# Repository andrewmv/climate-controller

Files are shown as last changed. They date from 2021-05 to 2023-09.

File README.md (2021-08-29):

# Home Assistant Climate Controller

A wifi-enabled replacement for line-level electric heat controller thermostats installed in standard single-gang US electrical junction boxes

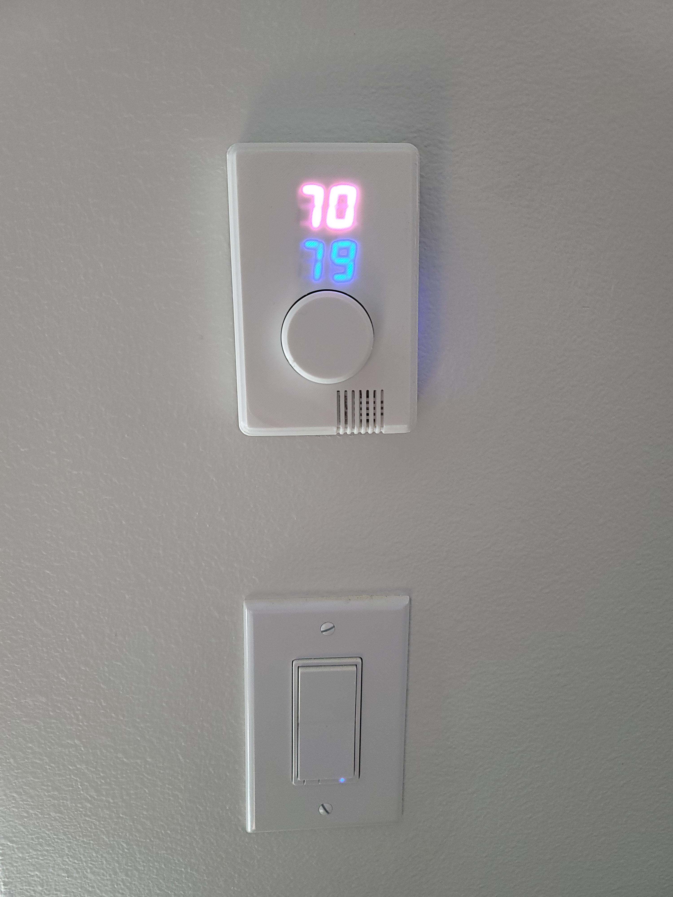
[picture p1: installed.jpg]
installed


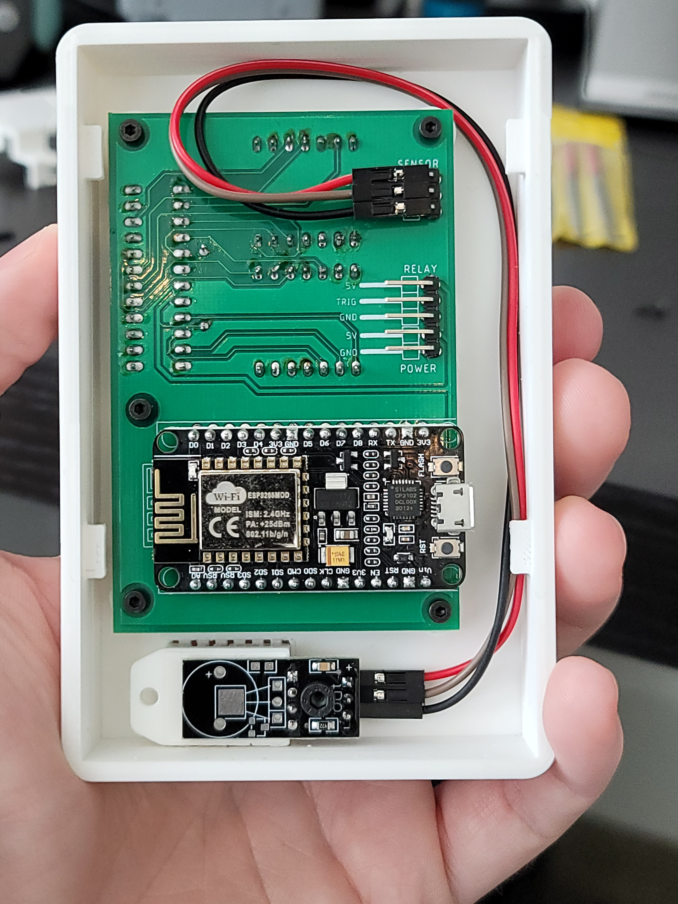
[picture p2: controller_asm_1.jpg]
controller_asm_1


## Enclosure

OpenSCAD sources and rendered STLs for 3D printing

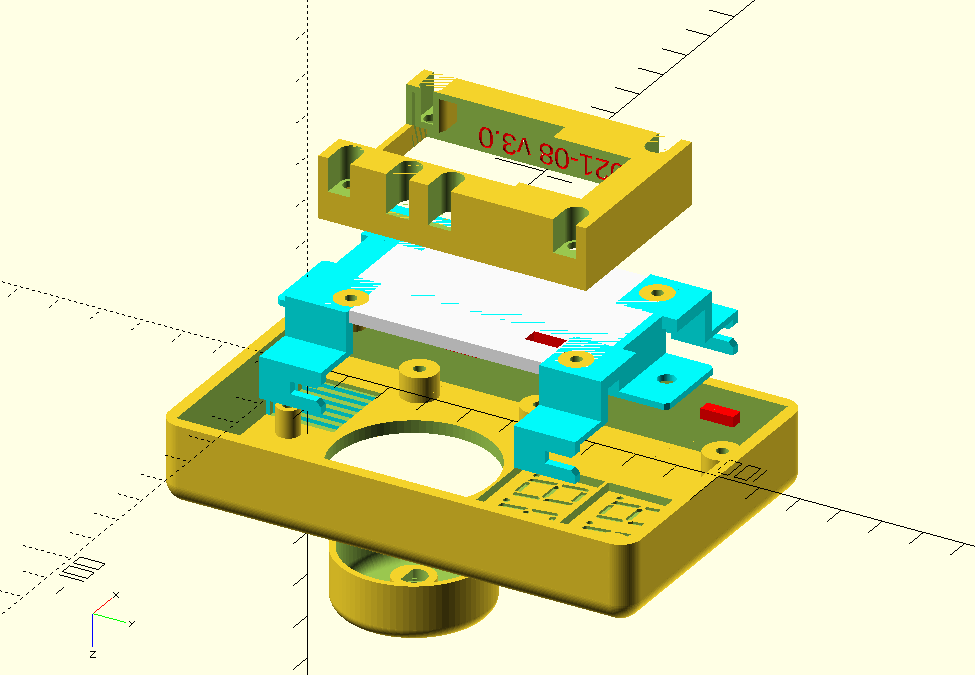
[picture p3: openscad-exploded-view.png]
openscad-exploded-view


## PCB

EagleCAD schematics, boards, and reqresuite libraries.

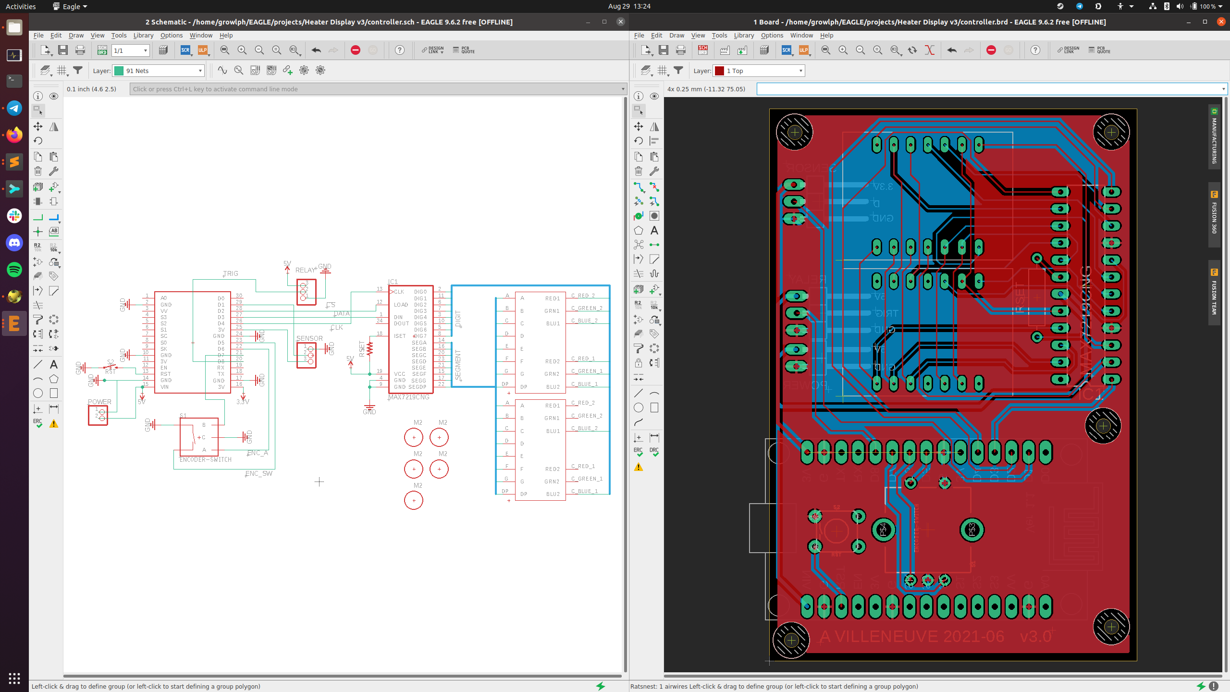
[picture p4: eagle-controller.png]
eagle-controller


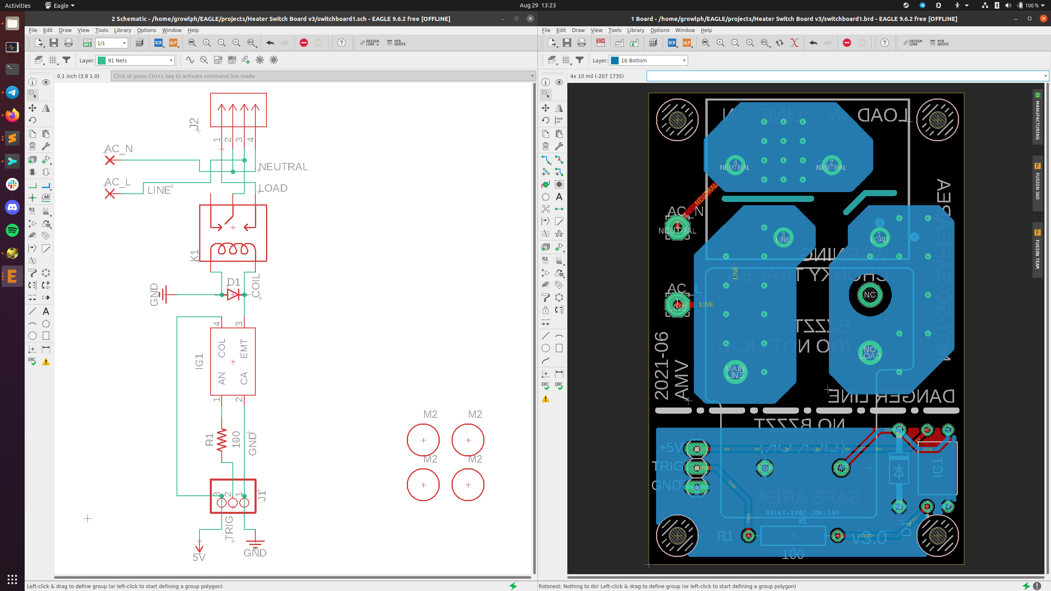
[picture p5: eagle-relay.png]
eagle-relay


## Software

Control software for ESPHome.io

## Reference

Part datasheets and vendor libraries

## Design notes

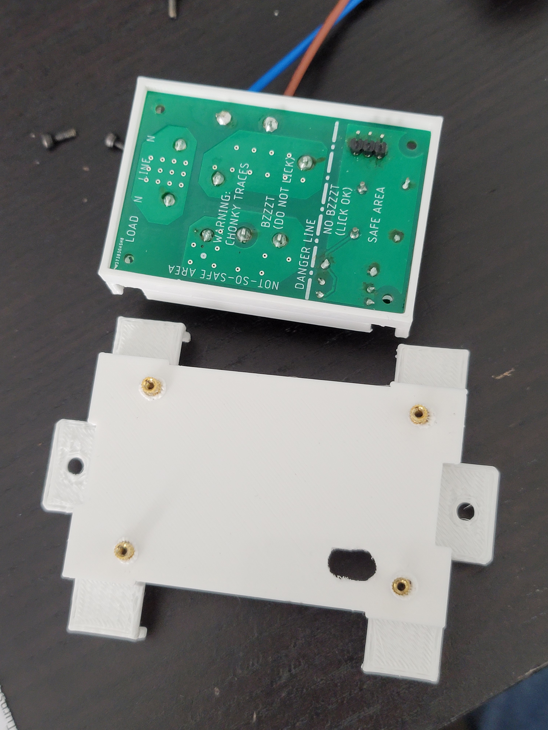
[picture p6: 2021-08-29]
relay_asm_1.jpg

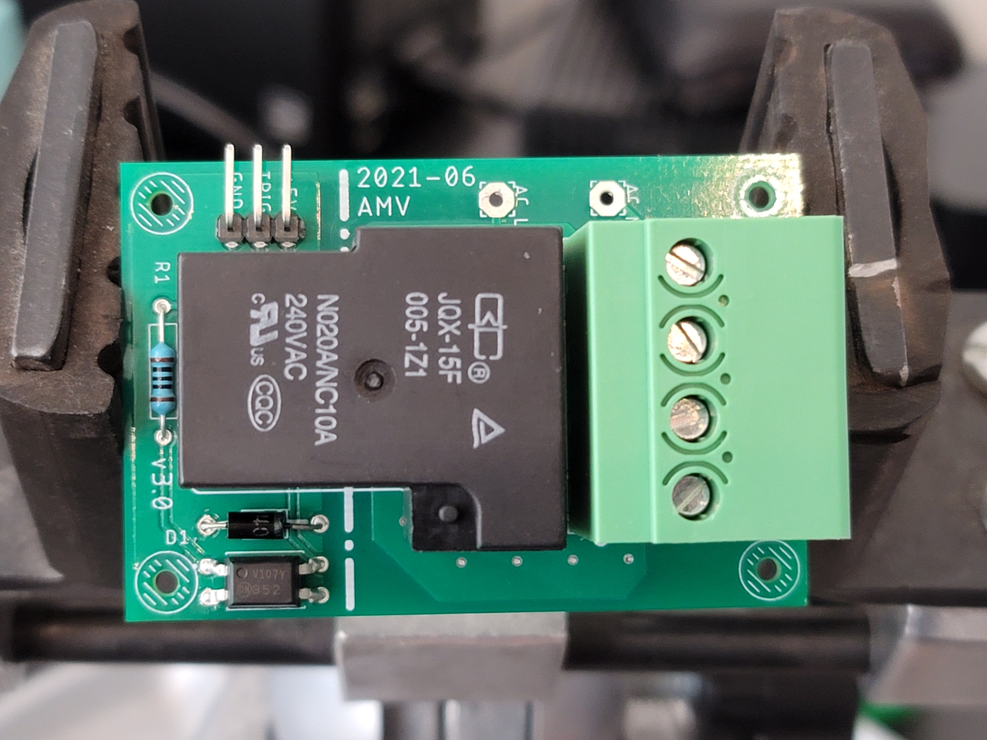
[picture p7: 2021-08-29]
finished_pop_relay_pcb.jpg

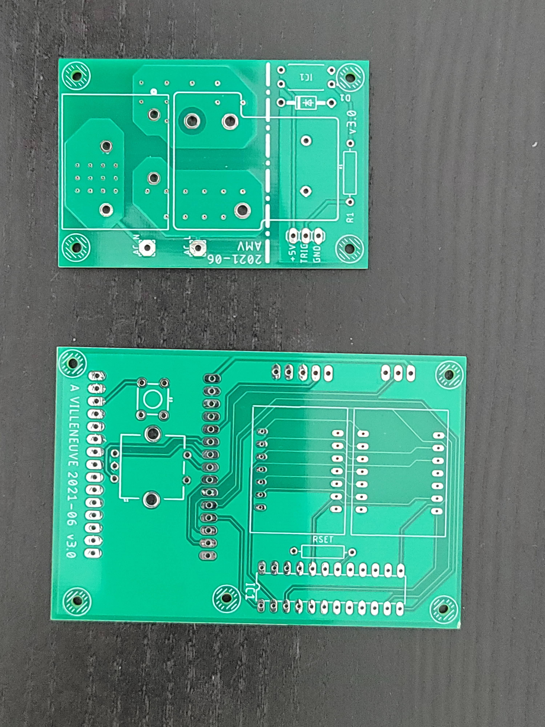
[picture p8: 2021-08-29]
finished_unpop_pcb.jpg

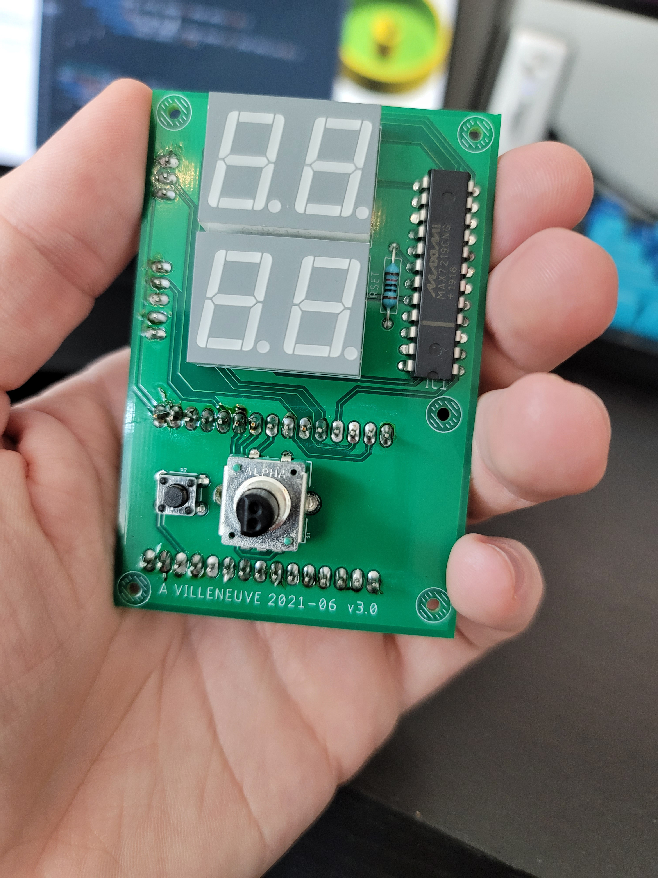
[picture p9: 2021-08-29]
finished_pop_cont_pcb.jpg

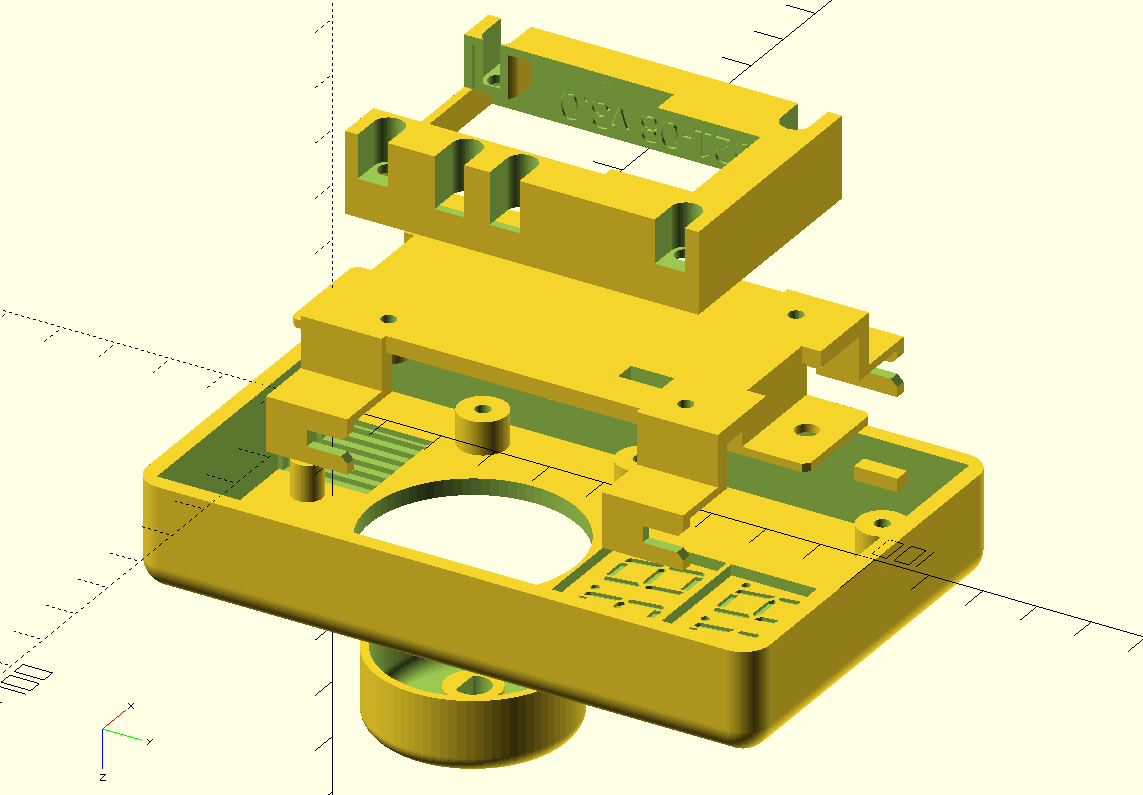
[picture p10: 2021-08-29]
openscad-explode-rendered.png

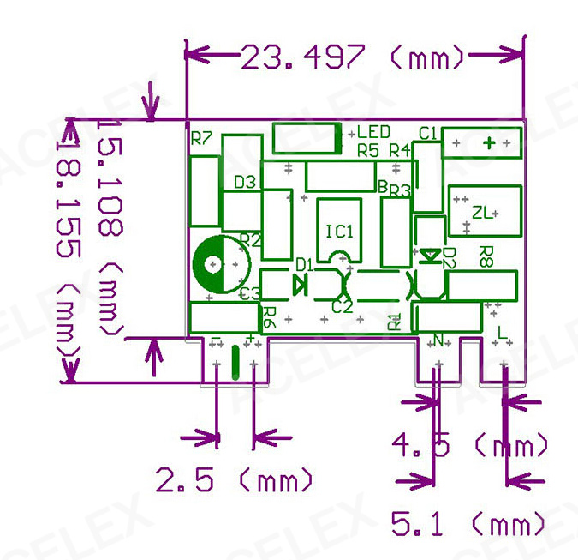
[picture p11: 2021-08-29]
Reference/PSU Dimensions.png

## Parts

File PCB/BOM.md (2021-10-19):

# Bill of Materials

| Quantity | Part | Link |
| --- | --- | --- |
| 1 | Maxim MAX7219 DIP | https://www.adafruit.com/product/453 |
| 1 | ACD8143 Segment Display | https://www.sparkfun.com/products/13999 |
| 1 | Subminiature tactile switch | https://www.sparkfun.com/products/97 |
| 3 | 0.1" headers (straight) | https://www.sparkfun.com/products/116 |
| 8 | 0.1" headers (right angle) | https://www.sparkfun.com/products/553 |
| 1 | ESP8266 Development board | https://www.amazon.com/gp/product/B07HF44GBT/ |
| 1 | FOD852300 Optoisolator | https://www.digikey.com/en/products/detail/onsemi/FOD852300/1054006 |
| 1 | Phoenix Contact 6.35mm terminal block connector | https://www.digikey.com/en/products/detail/phoenix-contact/1017516/9346596 |
| 1 | 20A Relay | https://www.sparkfun.com/products/10924 |
| 1 | Rotary Encoder | https://www.sparkfun.com/products/9117 |
| 1 | Axial Diode | |
| 1 | 100Ω Axial Resistor | |
| 1 | 33kΩ Axial Resistor | |
| 5 | M2 x 3mm brass threaded inserts | https://www.amazon.com/gp/product/B07LBQFNQD/ |
| 4 | M2 x 8mm brass threaded inserts | |
| 9 | M2 x 6mm screws | https://www.amazon.com/gp/product/B01FL88Y76/ |
| 1 | M3 x 6mm screw | |

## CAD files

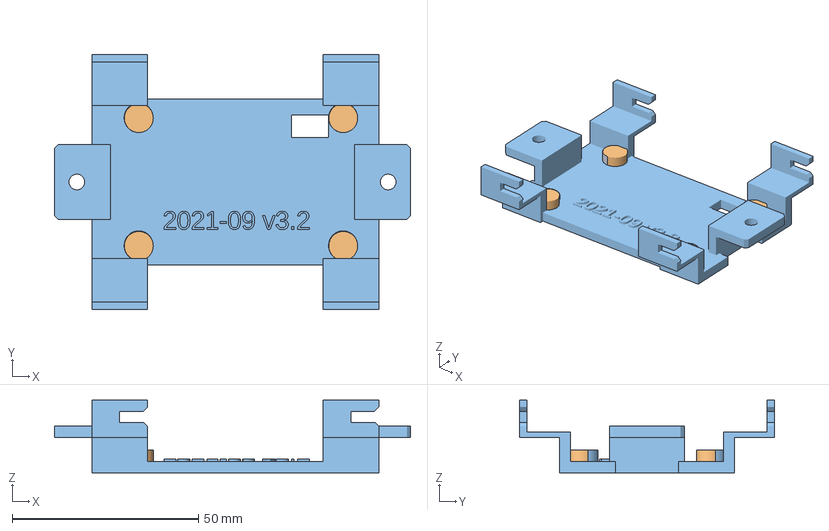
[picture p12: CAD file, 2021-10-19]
Enclosure/MSMV2E3D_climate_bracket.3mf
95.5 x 68.5 x 19.5 mm
climate_bracket_supports.stl
climate_bracket_supports.stl(1)
climate_bracket.stl(1)

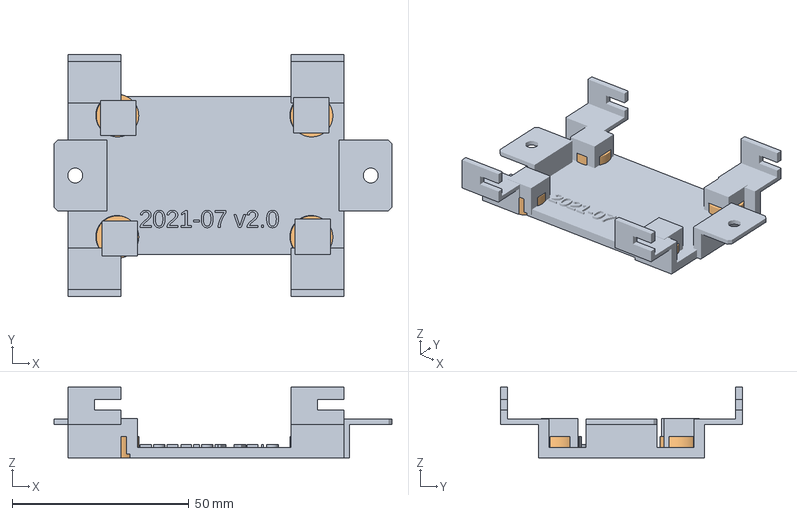
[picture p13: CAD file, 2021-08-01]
MSMV2E3D_climate_bracket.3mf
95.5 x 68.5 x 20.0 mm
climate_bracket.stl
climate_bracket_supports.stl

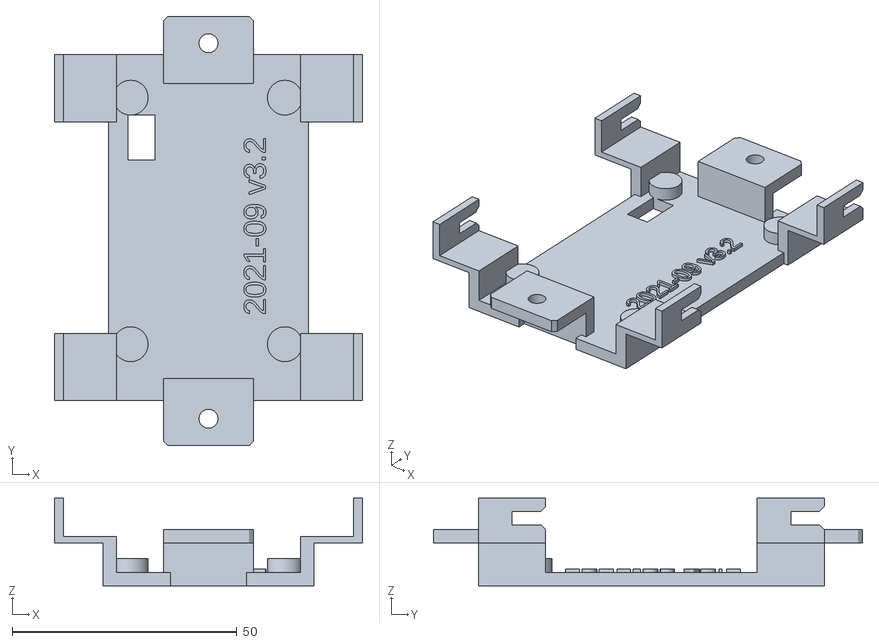
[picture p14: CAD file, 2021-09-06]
Enclosure/climate_bracket.stl
68.5 x 95.5 x 19.5

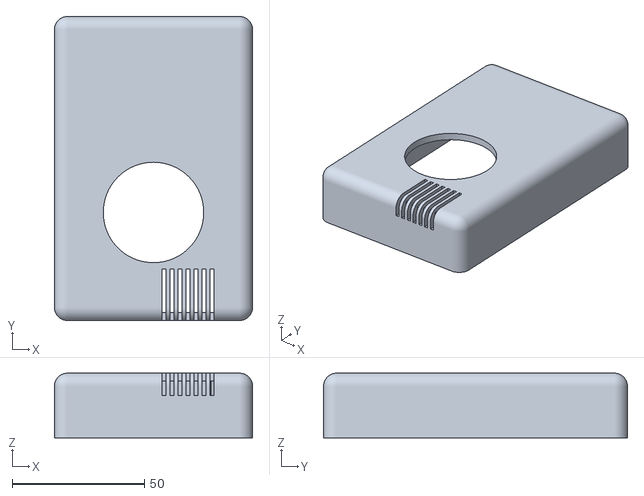
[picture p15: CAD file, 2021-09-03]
Enclosure/climate_faceplate.stl
75.0 x 115.0 x 24.5

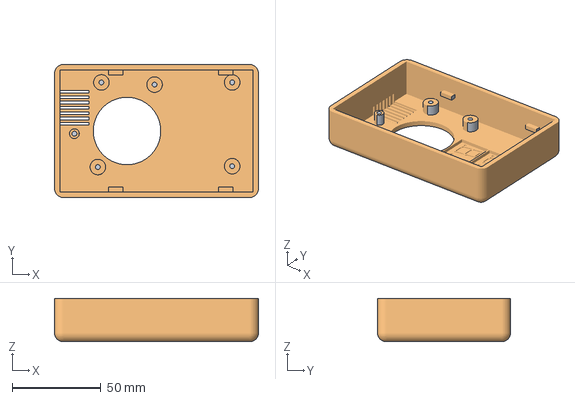
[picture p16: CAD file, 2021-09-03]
Enclosure/MSMV2E3D_climate_faceplate.3mf
115.0 x 75.0 x 24.5 mm
climate_faceplate_supports.stl
climate_faceplate.stl

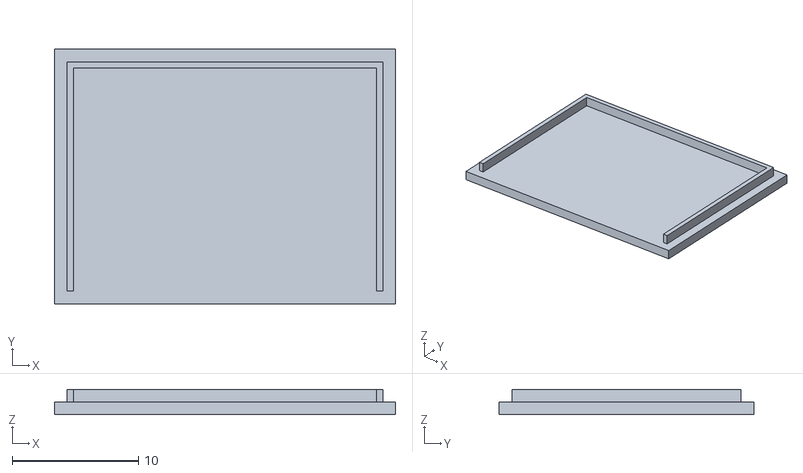
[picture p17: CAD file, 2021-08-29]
Enclosure/PSU_cover.stl
27.0 x 20.2 x 2.00

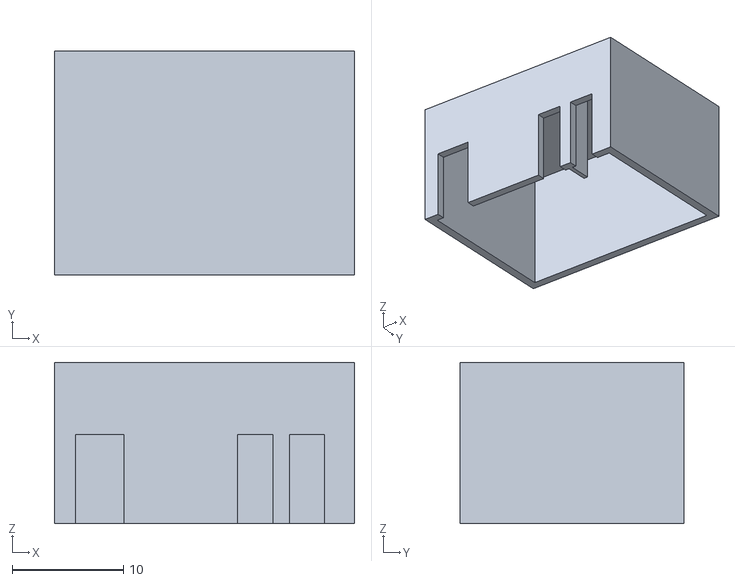
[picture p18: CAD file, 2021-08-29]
Enclosure/PSU.stl
27.0 x 20.2 x 14.5

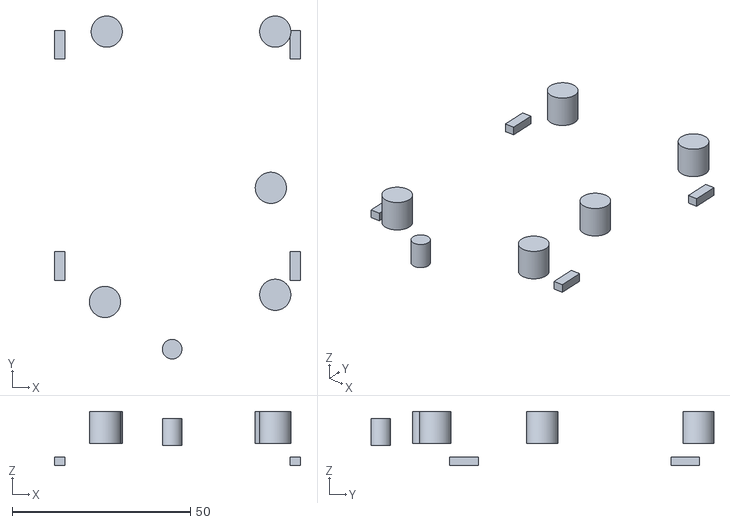
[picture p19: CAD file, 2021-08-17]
Enclosure/climate_faceplate_supports.stl
69.0 x 96.1 x 15.2

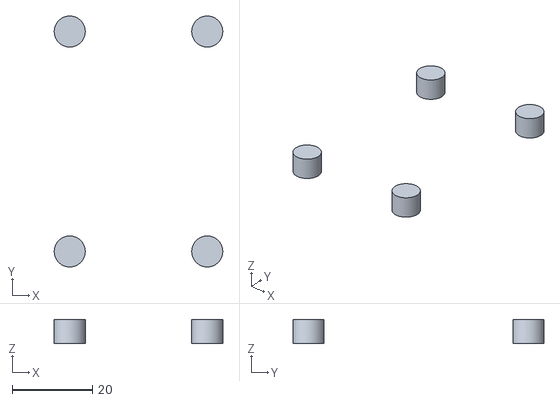
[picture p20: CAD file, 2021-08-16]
Enclosure/climate_bracket_supports.stl
42.0 x 62.6 x 6.10

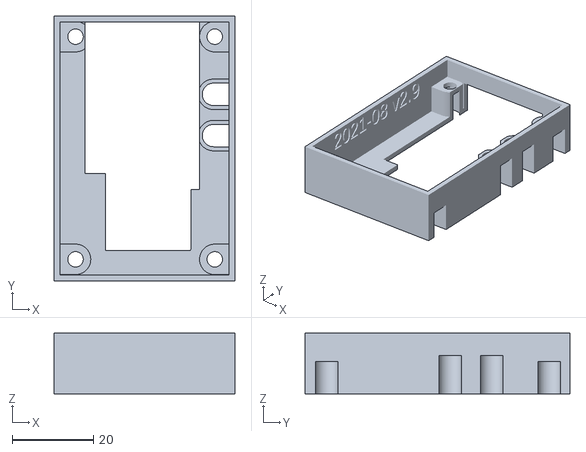
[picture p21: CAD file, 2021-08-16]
Enclosure/relay_cover.stl
44.6 x 65.2 x 15.0

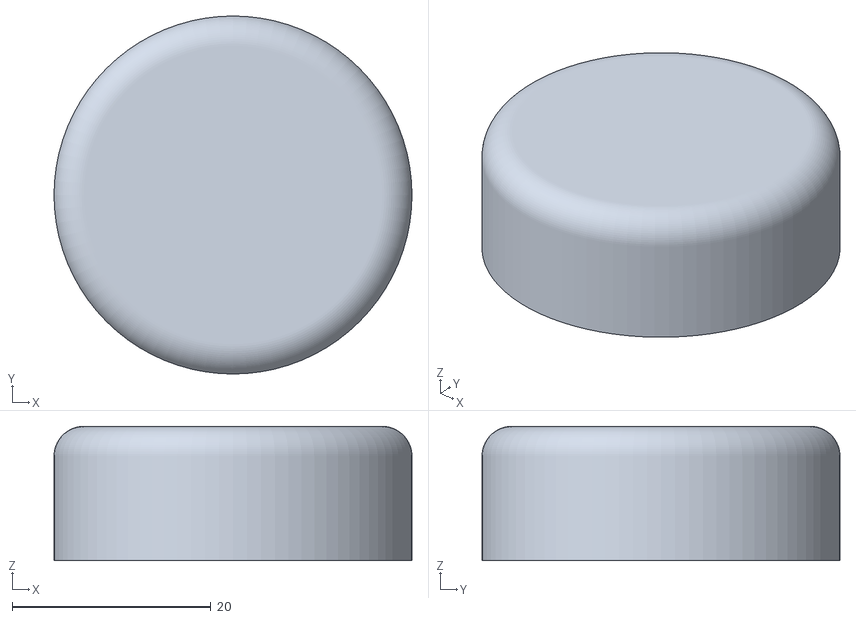
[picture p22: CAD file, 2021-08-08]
Enclosure/dial.stl
36.0 x 36.0 x 13.5

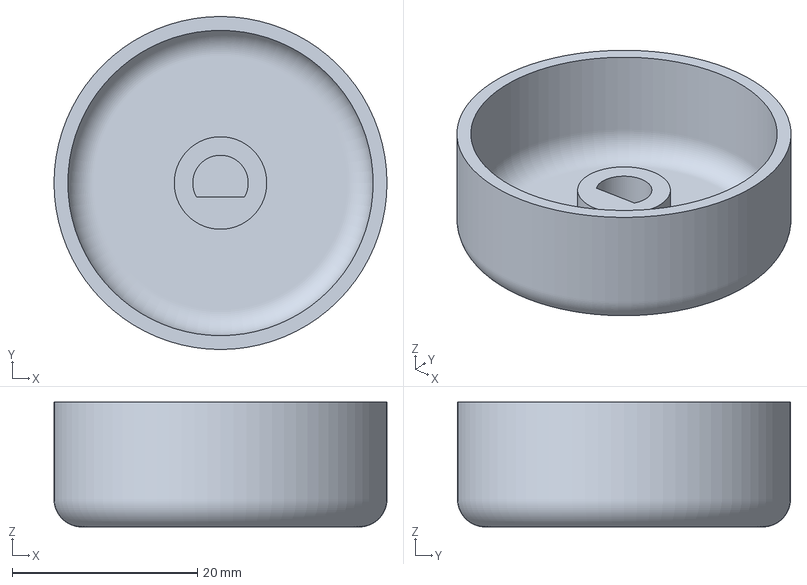
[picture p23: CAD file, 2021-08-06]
Enclosure/MSMV2E3D_dial.3mf
36.0 x 36.0 x 13.5 mm

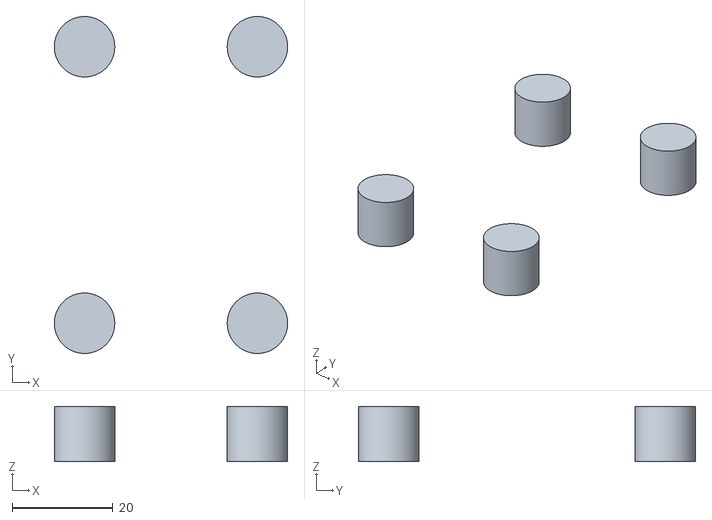
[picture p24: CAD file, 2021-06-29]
Enclosure/climate_bracket_nosupport.stl
46.3 x 66.8 x 11.0

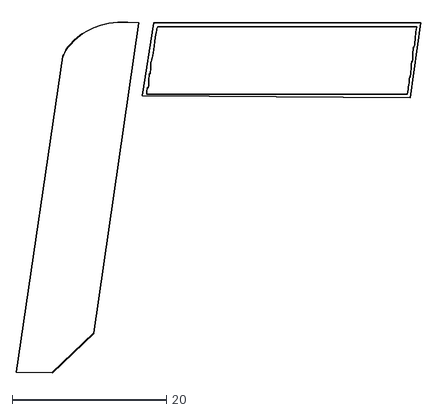
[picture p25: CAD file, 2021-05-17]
Enclosure/7-segment_layout.dxf
52.4 x 46.2

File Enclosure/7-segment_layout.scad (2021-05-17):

tol = 0.25;
xdigit=11.012;
ydigit=14.221;
xdim=25 + tol;
ydim=19.05 + tol;
zdim=1;
diffuse_thickness=0.25;
inter_digit=12.7;
xoff1 = 1;
xoff2 = xoff1 + inter_digit;
yoff = 2.5;
ridge_thickness = 1;
ridge_height = 1;

printer_layer_height=0.1313;

*difference() {
	translate([-ridge_thickness, -ridge_thickness, 0]) {
		cube(size=[xdim + (2 * ridge_thickness),
				   ydim + (2 * ridge_thickness),
				   zdim + ridge_height]);
	}
	cube(size=[xdim, ydim, zdim + ridge_height + 1]);
}

for(i = [2:1:6]) {
	translate([0, (ydim + 1) * (i - 2), 0]) {
		mirror([1,0,0]) {
			mod1(printer_layer_height * i);
		}
		translate([0, 0, 0]) {
			difference() {
				cube(size=[10, ydim, zdim]);
				removal_tab();
				translate([9,2,-1]) {
					mirror([1,0,0]) {
					linear_extrude(zdim + 2)
						text(str(i), 10);
					}
				}
			}
		}
	}
}

// number stencil bits
translate([0, (ydim + 1) * (4 - 2) + 6, 0]) 
	cube(size=[10, 1, zdim]);
translate([0, (ydim + 1) * (6 - 2) + 4.5, 0]) 
	cube(size=[10, 1, zdim]);

module removal_tab() {
	translate([10-2,ydim - 4, 0])
		rotate([0,45,0])
			cube(size=[2,4,4]);
}

// !color("red")	removal_tab();

// homing overlay
module mod1(d) {
	difference() {
		cube(size=[xdim, ydim, zdim]);
		translate([xoff1 + (tol/2),yoff + (tol/2),d])
			digit_channels(zdim);
		translate([xoff2 + (tol/2),yoff + (tol/2),d])
			digit_channels(zdim);
	}
}

module digit_channels(h) {
	linear_extrude(height=h, center=false, convexity=6) {
		import(file="7-segment_layout_scaled_90.svg", layer="layer2", dpi=96);
	}
}

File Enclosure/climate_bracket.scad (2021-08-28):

include <climate_enclosure.h>

//*** DIMENSIONS ***//

//*** ASSEMBLY ***//

if (render_supports) {
	supports();
} else {
	difference() {
		union() {
			if (render_placeholders) {
				placeholder_board();
				*color("grey", 0.5)	placeholder_jbox();
			}
			color("cyan")	jbox_mounting_ears();
			color("white")	relay_plate();
			color("blue")	label();
			*color("pink")	sidewalls();
			color("cyan")	face_hooks();
		}
		color("red")	relay_passthrough();
		translate([0,0,-1])
			relay_mounting_stems(0);
	}
	relay_mounting_stems(mounting_hole_r);
}


//*** MODULES ***//

module sidewalls() {
	rotate([0,180,0]) {
		translate([	-relay_dim.x/2,
					relay_pos.y,
					-relay_pos.z]) {
			difference() {
				cube(size=[	relay_dim.x,
							relay_dim.y,
							mounting_hole_depth]);
				translate([	relay_sidewalls,
							relay_sidewalls,
							-1]) {
					cube(size=[	relay_dim.x - (2 * relay_sidewalls),
								relay_dim.y - (2 * relay_sidewalls),
								mounting_hole_depth + 2]);
				}
				for(i = [0:len(relay_mounting_holes)-1]) {
					translate(relay_mounting_holes[i]) {
						mounting_stem(mounting_hole_depth + thickness,
							hole_r = 0);
					}
				}
			}
		}
	}
}

module relay_mounting_stems(r) {
	stem_depth = relay_threaded_insert_depth - relay_pcb_inset + relay_dim.z + 2;
	translate([jbox_dim.x/2,0,stem_depth]) { 
		rotate([0,0,180]) {
			translate([relay_pos.x, -relay_pos.y - relay_dim.y, relay_pos.z]) {
				for(i = [0:len(relay_mounting_holes)-1]) {
					translate(relay_mounting_holes[i]) {
						translate([0,0, 0]) {
							rotate([180,0,0]) {
								mounting_stem(stem_depth, stem_r = relay_mounting_stem_r, hole_r = r);
							}
						}
					}
				}
			}
		}
	}
}

module supports() {
	relay_mounting_stems(0);
}

module label() {
	translate([	relay_pos.x + 8,
				relay_pos.y + 10,
				relay_pos.z+thickness])
		rotate([0,0,90])
			linear_extrude(0.75)
				text(label_text, size=label_size);
}

module face_hooks() {
	for(i = [0:len(face_hook_pos[1])-1]) {
		translate([0,face_hook_pos[1][i],relay_pos.z]) {
			face_hook_right();
		}
	}
	for (i = [0:len(face_hook_pos[0])-1]) {
		translate([0,face_hook_pos[0][i],relay_pos.z]) {
			face_hook_left();
		}
	}
}

module face_hook_left() {
	mirror([1,0,0])
		face_hook_right();
}

module face_hook_right() {
	//difference() {
		translate([jbox_dim.x/2 - face_hook_dim_1.x - face_hook_jbox_clearance - thickness,0,0]) {
			if (!render_supports) {
				cube(size=face_hook_dim_1);
			}
			translate([face_hook_dim_1.x,0,0]) {
				cube(size=face_hook_dim_2);
				translate([0,0,face_hook_dim_2.z]) {
					cube(size=face_hook_dim_3);
					translate([face_hook_dim_3.x,0,0]) {
						difference() {
							cube(size=face_hook_dim_4);
							translate(face_hook_slot_pos) {
								cube(size=face_hook_slot_dim);
								translate([	0,
											12,
											-5.5]) {
									rotate([45,0,0]) {
										cube(size=10);
									}
								}
							}
						}
					}
				}
			}
		}
}

module placeholder_jbox() {
	translate([-jbox_dim.x/2,0,-jbox_dim.z]) {
		difference() {
			translate([-3,-3,-3])
				cube([jbox_dim.x + 6,
					   jbox_dim.y + 6,
					   jbox_dim.z + 3]);
			cube([jbox_dim.x, jbox_dim.y, jbox_dim.z + 1]);
		}
		translate([(jbox_dim.x/2) - (jbox_mount_dim.x/2), 0, 0]) {
			cube(jbox_mount_dim);
			translate([0,jbox_dim.y - jbox_mount_dim.y ,0])
				cube(jbox_mount_dim);
		}
	}
}

module placeholder_board() {
	rotate([0,180,0])
		translate([-jbox_dim.x/2,0,2 * -relay_pos.z + relay_pcb_inset - relay_dim.z])
			color("green") {
				translate(relay_pos) {
					difference() {
						cube(size=relay_dim);
						for(i = [0:len(relay_mounting_holes)-1]) {
							translate([0,0,-1])
							translate(relay_mounting_holes[i]) {
								linear_extrude(zdim) {
									circle(r=2.1);
								}
							}
						}
					}
				}
			}
}

module relay_plate() {
	rotate([0,180,0])
		translate([0,0,2 * -relay_pos.z - thickness])
			translate([-jbox_dim.x/2,0,0]) 
			translate([relay_pos.x - relay_cover_thickness,relay_pos.y,relay_pos.z]) {
				cube(size=[relay_dim.x + (2 * relay_cover_thickness), relay_dim.y, thickness]);
			}
}

module relay_passthrough() {
	rotate([0,180,0])
		translate([0,0,2 * -relay_pos.z - thickness ])
			translate([-jbox_dim.x/2,0,0]) 
			translate([relay_pos.x - relay_cover_thickness,relay_pos.y,relay_pos.z]) {
				translate([	relay_dim.x - relay_passthrough_pos.x,
							relay_dim.y - relay_passthrough_pos.y] ) {
					cube(size=relay_passthrough_dim, center=true);
				}
			}
}

module jbox_mounting_ears() {
	translate([0,jbox_hole_inset,0]) {
		jbox_mounting_ear();
		translate([0,jbox_screw_distance,0]) {
			rotate([0,0,180]) {
				jbox_mounting_ear();
			}
		}
	}
	translate([-jbox_ear_width/2, jbox_mount_dim.y, relay_pos.z]) {
		cube([jbox_ear_width, 
			  jbox_dim.y - (2 * jbox_mount_dim.y) - 2, 
			  thickness]);
	}
}

module jbox_mounting_ear() {
	linear_extrude(jbox_ear_thickness) {
		difference() {
			intersection() {
				square([jbox_ear_width, 12], center=true);
				translate([0, jbox_ear_pleatau, 0]) {
					rotate([0,0,45]) {
						square([50,50]);
					}
				}
			}
			circle(r=jbox_screw_dia);
		}
	}
	translate([-jbox_ear_width/2, jbox_mount_dim.y - jbox_hole_inset, relay_pos.z]) {
		cube([jbox_ear_width, thickness, -relay_pos.z + jbox_ear_thickness]);
	}
}

module fplate_mount() {

}

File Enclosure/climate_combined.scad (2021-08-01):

include <climate_bracket.scad>
include <climate_faceplate.scad>
include <relay_cover.scad>
include <dial.scad> 

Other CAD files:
Enclosure/7-segment_diffuser_test.stl
Enclosure/7-segment_layout_scaled.dxf
Enclosure/climate_faceplate.scad
Enclosure/PSU.scad
Enclosure/PSU_cover.scad
Enclosure/dial.scad
Enclosure/relay_cover.scad

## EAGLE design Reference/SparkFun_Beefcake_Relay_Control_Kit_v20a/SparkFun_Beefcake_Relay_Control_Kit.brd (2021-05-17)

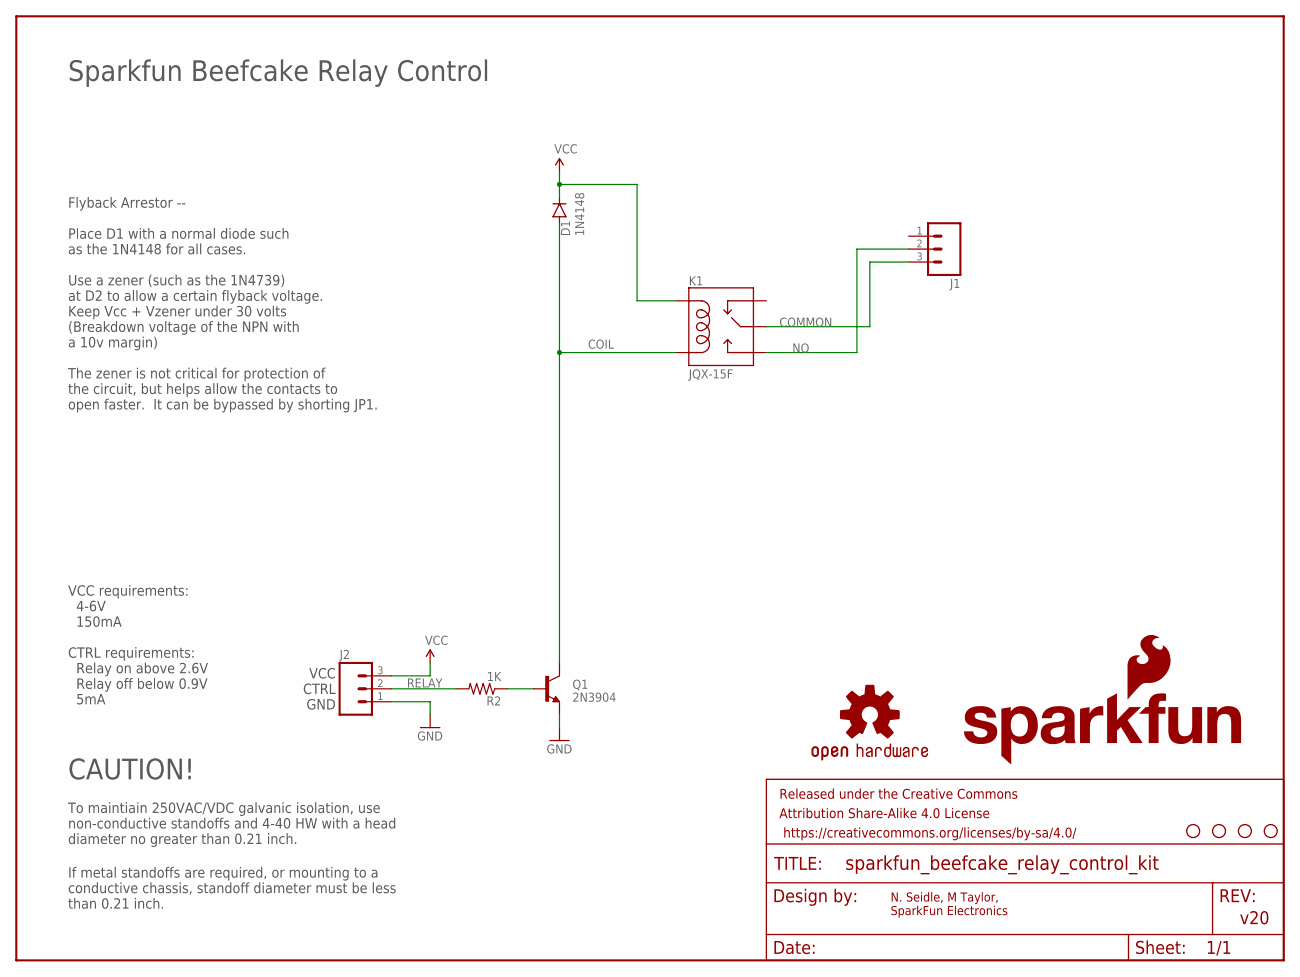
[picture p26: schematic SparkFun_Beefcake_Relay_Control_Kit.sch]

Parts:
D1: 1N4148; DIODE-1N4148-KIT
FRAME2: FRAME-LETTER; CREATIVE_COMMONS
J1: M03-SCREW-5MM; SCREWTERMINAL-5MM-3
J2: M03SCREW; SCREWTERMINAL-3.5MM-3
K1: JQX-15F; RELAY-T90
LOGO1: SFE_LOGO_NAME_FLAME.1_INCH; SFE_LOGO_NAME_FLAME_.1
Q1: 2N3904; TO-92-EZ
R2: 1K; AXIAL-0.3EZ
U$3, U$4, U$5, U$7: STAND-OFF
U$12: OSHW-LOGOS; OSHW-LOGO-S

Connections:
COIL: D1.A, K1.COIL2, Q1.3 (C)
COMMON: J1.3, K1.MAIN
GND: J2.1, Q1.1 (E)
unnamed: Q1.2 (B), R2.P$1 (1)
NO: J1.2, K1.NO
RELAY: J2.2, R2.P$2 (2)
VCC: D1.C, J2.3, K1.COIL1

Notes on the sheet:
N. Seidle, M Taylor, SparkFun Electronics
v20
Flyback Arrestor -- Place D1 with a normal diode such as the 1N4148 for all cases. Use a zener (such as the 1N4739) at D2 to allow a certain flyback voltage. Keep Vcc + Vzener under 30 volts (Breakdown voltage of the NPN with a 10v margin) The zener is not critical for protection of the circuit, bu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
To maintiain 250VAC/VDC galvanic isolation, use non-conductive standoffs and 4-40 HW with a head diameter no greater than 0.21 inch.
CAUTION!
If metal standoffs are required, or mounting to a conductive chassis, standoff diameter must be less than 0.21 inch.
VCC requirements: 4-6V 150mA CTRL requirements: Relay on above 2.6V Relay off below 0.9V 5mA
VCC CTRL GND
Sparkfun Beefcake Relay Control

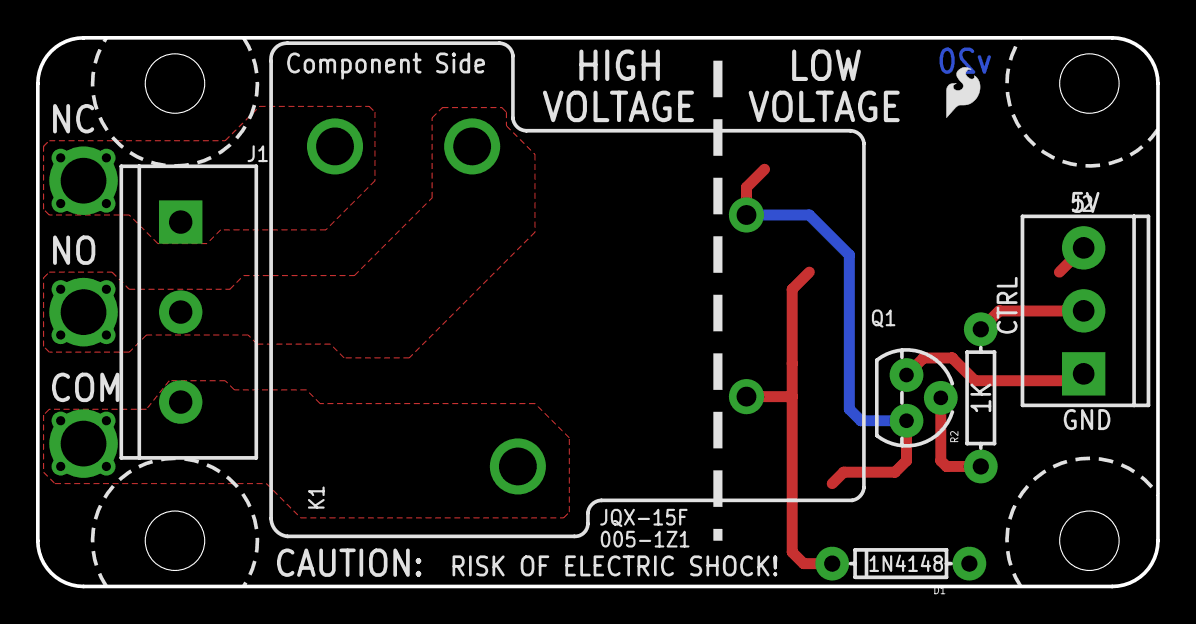
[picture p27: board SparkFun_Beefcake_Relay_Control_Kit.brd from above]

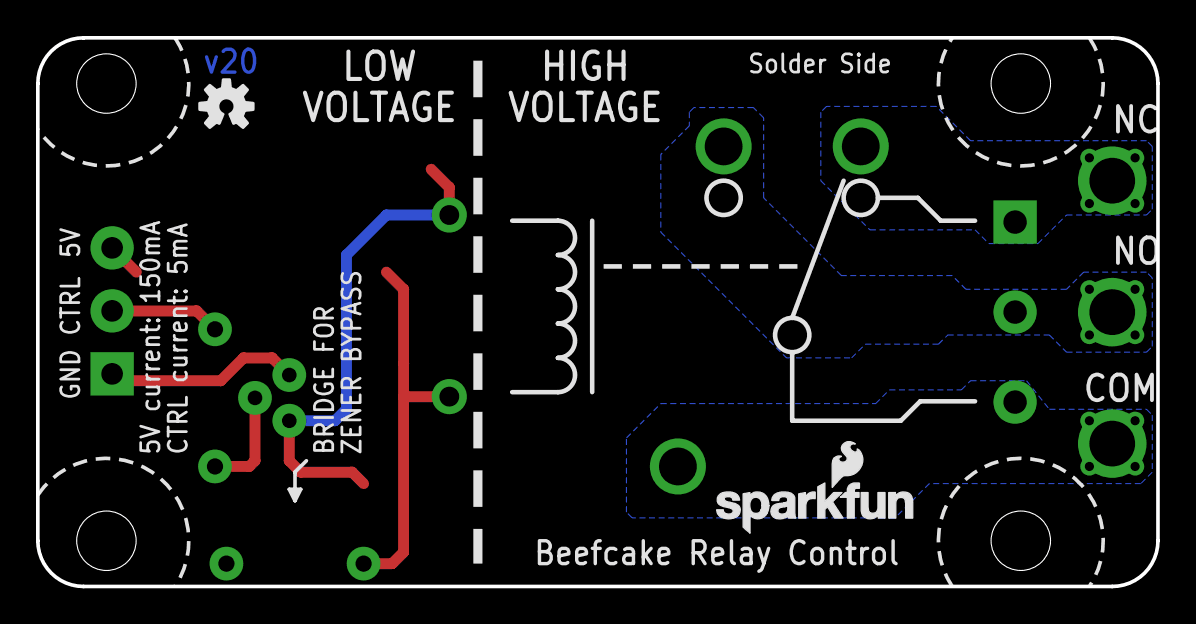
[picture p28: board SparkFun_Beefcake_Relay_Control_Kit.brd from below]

Board: 2 copper layers, 62.2 x 30.5 mm, 14 parts (2 on the bottom side), 7 nets.

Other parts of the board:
U$11: SFE-LOGO-FLAME

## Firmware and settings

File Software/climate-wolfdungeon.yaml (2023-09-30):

esphome:
  name: wolfdungeon_thermostat
  on_boot:
    priority: 500
    then:
      - lambda: |-
          id(wolfdungeon_thermostat).target_temperature = id(last_known_target_temperature);
          id(boot_complete) = true;

esp8266:
  board: nodemcuv2
  restore_from_flash: true

preferences:
  flash_write_interval: 5min

wifi:
  ssid: !secret ssid  
  password: !secret wappw

  # Enable fallback hotspot (captive portal) in case wifi connection fails
  ap:
    ssid: "Dungeon Climate Fallback Hotspot"
    password: !secret hotspotpw

captive_portal:

# Enable logging
logger:

# Enable Home Assistant API
api:
  password: !secret apipw

ota:
  password: !secret apipw

### PIN MAPPINGS ###

# D0      - Unused
# D1      - Thermosensor
# D2      - Display Enable
# D3(OUT) - Display Data
# D4(OUT) - Display Clock
# D5      - Encoder Switch
# D6      - Encoder Clock
# D7      - Encoder Signal
# D8(OUT) - Heater Relay

### BEGIN GOOD STUFF ###

globals:
    # We need to suppress calls to display.update() until the display has
    # been fully set up, or we'll get segfaults
  - id: boot_complete
    type: bool
    restore_value: false
    initial_value: 'false'
  - id: system_on
    type: bool
    restore_value: true
    initial_value: 'false'
  - id: display_enabled
    type: bool
    restore_value: true
    initial_value: 'true'
  - id: last_known_target_temperature
    type: float
    restore_value: true
    initial_value: '23.33'

# MAX7219 Configuration
spi:
  clk_pin: D4
  mosi_pin: D3

display:
  - platform: max7219
    id: temp_display
    cs_pin: D2
    num_chips: 1
    reverse_enable: true
    lambda: |-
      if (id(display_enabled)) {
        it.printf(0, "%2.0f", id(wolfdungeon_thermostat).current_temperature * (9.0/5.0) + 32.0);  // Bottom Blue Display
        if (id(system_on)) {
          if (id(heater).state) {
            it.printf(6, "%2.0f", id(wolfdungeon_thermostat).target_temperature * (9.0/5.0) + 32.0); // Top Red Display
          } else {
            it.printf(6, "%2.0f", id(wolfdungeon_thermostat).target_temperature * (9.0/5.0) + 32.0); // Top Red Display
            it.printf(2, "%2.0f", id(wolfdungeon_thermostat).target_temperature * (9.0/5.0) + 32.0); // Top Blue Display
            it.printf(4, "%2.0f", id(wolfdungeon_thermostat).target_temperature * (9.0/5.0) + 32.0); // Top Green Display
          }
        }
      }

sensor:
  - platform: dht
    model: DHT22
    pin: D1
    temperature:
      name: "Wolf Dungeon Thermostat Temperature"
      id: wolfdungeon_sensor
      unit_of_measurement: "°C"
      filters:
       - calibrate_polynomial:
          degree: 2
          datapoints:
            - 21.89 -> 19.78
            - 23.61 -> 20.72
            - 25.61 -> 22.22
            - 27.89 -> 22.11
            - 28.28 -> 23.11
    humidity:
      name: "Wolf Dungeon Thermostat Humidity"
    update_interval: 10s
  - platform: wifi_signal
    name: "Wolf Dungeon Thermostat Wifi"
    update_interval: 60s
  - platform: rotary_encoder
    id: rot_enc
    internal: true
    # min_value: 10
    # max_value: 37
    on_clockwise:
      - script.execute: display_sleep_timer
      - lambda: |-
          if ((id(wolfdungeon_thermostat).mode == CLIMATE_MODE_HEAT) && (id(wolfdungeon_thermostat).target_temperature < 32.22)) {
            id(wolfdungeon_thermostat).target_temperature += 0.555;
            id(temp_display).update();
          }
      - script.execute: set_point_timer
    on_anticlockwise:
      - script.execute: display_sleep_timer
      - lambda: |-
          if ((id(wolfdungeon_thermostat).mode == CLIMATE_MODE_HEAT) && (id(wolfdungeon_thermostat).target_temperature > 10.0)) {
            id(wolfdungeon_thermostat).target_temperature -= 0.555;
            id(temp_display).update();
          }
      - script.execute: set_point_timer
    pin_a:
      number: D6
      mode: INPUT_PULLUP
    pin_b: 
      number: D7
      mode: INPUT_PULLUP
  - platform: template
    name: "Wolf Dungeon Heater Power"
    id: wolf_dungeon_heater_power
    unit_of_measurement: kW
    lambda: |-
      if (id(heater).state) {
        return 0.5; // 2.1A, 500W for 120V heater
      } else {
        return 0.0;
      }     
  - platform: total_daily_energy
    name: "Wolf Dungeon Heater Consumption"
    power_id: wolf_dungeon_heater_power

binary_sensor:
  - platform: gpio
    id: rot_sw
    pin: 
      number: D5
      mode: INPUT_PULLUP
    internal: true
    filters:
      - invert: 
    on_click:
      - script.execute: display_sleep_timer
      - lambda: |-
          auto call = id(wolfdungeon_thermostat).make_call();
          if (id(wolfdungeon_thermostat).mode == CLIMATE_MODE_HEAT) {
            call.set_mode("OFF");
          } else {
            call.set_mode("HEAT");
          }
          call.perform();

output:
  - platform: template
    id: display_timer_enabled
    type: binary
    write_action:
      - script.execute: display_sleep_timer
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

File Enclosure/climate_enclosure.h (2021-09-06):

//*** DIMENSIONS ***//
x = 0; y = 1; z = 2;	// simplify array references
printer_layer_height=0.1313;
tol = 0.25;				// tolerance
$fn = 80;				// facet count for curves

label_text = "2021-09 v3.2";
label_size = 5;

// Include non-printing placeholder compoenents
render_placeholders = false;

// Only render mesh overlap structures
render_supports = false;

// Junction Box
jbox_dim = [51,92,82];
jbox_screw_distance = 83.5; 
jbox_screw_dia = 2.1;	
jbox_ear_width = 20;
jbox_ear_thickness = 3;
jbox_ear_pleatau = -15;
jbox_hole_inset = 4;
jbox_mount_dim = [15, 10, jbox_dim.z];

// Dial
dial_pos = [23.63,19.52];
dial_r = 18;
dial_bezel_r = 3;
dial_depth = 10.5;
dial_walls = 1.5;
dial_shaft_depth = 5;
dial_shaft_r = 10 / 2;
dial_hole_r = 6.25 / 2;
dial_hole_cut = (dial_hole_r * 2) - 4.75;
dial_faceplate_tol = 1.0;

// Faceplate
face_pos = [0, -5, 0];
thickness = 3;
corner_r = 10;
// brim_thickness = 13.5;
brim_thickness = 19.5 + 5;
display_thickness = 8; 
display_window_layers = 3;
display_window_thickness = display_window_layers * printer_layer_height;
display_window_depth = 1;
display_pos = [[10.93,39.44],[10.93,59.76]];
display_dim = [25.4,19,display_thickness];
display_tolerance = 0.25;
xdim = 75; //placeholder
ydim = 115;
zdim = display_thickness + display_window_depth;
yoff = -10;

// MAX IC keepout
max_pos = [47.20,55.95]; // centered
max_dim = [10,34,4];

// Control PCB
pcb_dim = [54.8,82.29,1.6];
pcb_pos = [
	(xdim / 2) - dial_pos.x,
	(ydim / 2) - (pcb_dim.y / 2) + 5,
	zdim
];
diffuse_inter_digit=12.7;
diffuse_xoff1 = 1;
diffuse_xoff2 = diffuse_xoff1 + diffuse_inter_digit;
diffuse_yoff = 2.5;

mounting_holes = [
	[3.31,3.08],
	[49.78,35.05],
	[51.01,5.08],
	[3.81,78.81],
	[51.01,78.81]
];

// ESP Backpack
esp_header_dim = [3,38,3];
esp_header_offset = 6;
esp_pos = [23.43,19.59,pcb_dim.z+esp_header_dim.z];
esp_dim = [48,26,4];

mounting_stem_r = 8.75/2;	
relay_mounting_stem_r = 7.75/2;	
mounting_hole_r = 2.75/2;		//for M2 screws
//mounting_hole_depth = 5;	//for 6mm long screws
mounting_stem_support_height = zdim;
mounting_stem_support_base = zdim;
mounting_stem_support_thickness = 2;

hook_dim = [3,20,30];
hook_cut_pos = [-1,10,3];
hook_cut_dim = [3, 10];
hook_cut_height = 20;
hook_cut_angle = 2;

// RELAY BOARD

relay_dim = [41.58,62.22,1.6];
relay_pos = [(jbox_dim.x / 2) - (relay_dim.x / 2),
			 jbox_mount_dim.y + 7,
			 -9.5];
relay_mounting_holes = [
	[3.81,3.81],
	[38.1,3.81],
	[3.81,58.65],
	[38.1,58.65]
];
relay_cover_height = 15.0;
relay_cover_thickness = 1.5;
relay_cover_mount_stem_r = 3.75;
relay_cover_mount_hole_r = 1.9;
relay_cover_mount_thickness = 1;
relay_sidewalls = 1.5;	 //TODO, merge this with thickness
relay_pcb_inset = 5.5;
relay_threaded_insert_depth = 8; //For M2x8x3.5 inserts
// NOTE: the following amount of the threaded brass insert should
// be left protruding:
// relay_pcb_inset - relay_dim.z = 5.5 - 1.6 = 3.9

// array of tuples, [pos,length]
// relay_conn_openings = [
// 	[8.0,9.0],
// 	[32.0,4],
// 	[42.5,4]
// ];
relay_actap_pos = [ [relay_dim.x-3.81,34.29],[relay_dim.x-3.81,44.45] ];
relay_passthrough_pos = [6.35 - 2,13.7 - 1];
relay_passthrough_dim = [4+2,8+2,10];
relay_conn_height=relay_pcb_inset - relay_dim.z;

// DHT SENSOR
dht_dim = [20.2,16.4,9.4];
dht_pos = [xdim - dht_dim.x - thickness - 11,
		   thickness, 
		   thickness - 1];
dht_slot_dim = [1.5,dht_dim.y + thickness,dht_dim.z];
dht_slot_spacing = 1.5;

// FACEPLATE HOOKS
face_hook_tol = 0.25;
face_hook_thickness = 3;
face_hook_width = 15;
face_hook_jbox_clearance = 2;
face_hook_dim_4 = [ 2,15, 10];
face_hook_overreach = (xdim / 2) - (jbox_dim.x / 2) - face_hook_dim_4.x - face_hook_tol;
face_hook_dim_1 = [12,
				   face_hook_width, 
				   thickness];
face_hook_dim_2 = [ thickness,
					face_hook_width,
					-relay_pos.z];
face_hook_dim_3 = [face_hook_overreach + face_hook_jbox_clearance,
				   15, 
				   1.5];
face_hook_slot_dim = [2 + 2, 15/2 + 1,3];
face_hook_slot_pos = [-1,15/2,4];
face_hook_pos = [
	[8, 70],	// left side
	[8, 70]	// right side
];
face_hook_tab_dim = [3,
					 8,
					 face_hook_slot_dim.z - (face_hook_tol * 2)];

// BEZEL

bezel_r = 5;

// MODULES

module mounting_stem(depth, stem_r = mounting_stem_r, hole_r = mounting_hole_r) {
	difference() {
		linear_extrude(depth) {
			circle(stem_r);
		}
		translate([0,0,2]) {
			linear_extrude(depth + 1) {
				circle(hole_r);
			}
		}
	}
	// stem_support(0);
	// stem_support(90);
	// stem_support(180);
	// stem_support(270);
}

//support triangle
support_points = [
	[0,0],
	[0, mounting_stem_support_height],
	[mounting_stem_support_base, 0]
];
support_paths = [[0, 1, 2]];

module stem_support(rotation) {
	rotate([90,0,rotation]) {
		translate([mounting_stem_r - 1,0,-mounting_stem_support_thickness / 2]) {
			linear_extrude(mounting_stem_support_thickness) {
				polygon(points=support_points, paths=support_paths);
			}
		}
	}
}

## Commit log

2021-05-26 PCB Pin Mapping
2021-05-26 Fixed pin mapping
2021-06-01 Checked in faceplate SCAD
    [climate_faceplate.scad]
2021-06-12 Changed some code
    [climate_faceplate.scad]
2021-06-23 DHT sensor bracket
    [climate_bracket.scad, climate_combined.scad, climate_faceplate.scad]
2021-06-23 Faceplate hooks
    [climate_bracket.scad]
2021-06-23 Faceplate hook refactoring
    [climate_bracket.scad, climate_faceplate.scad]
2021-06-23 Face hook tabs
    [climate_faceplate.scad]
2021-06-24 DHT Slots
    [climate_bracket.scad, climate_faceplate.scad]
2021-06-24 Label text, mesh fixes
    [MSMV2E3D_climate_bracket.3mf, climate_bracket.scad, climate_bracket.stl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]
2021-06-25 Faceplate bezel, support mesh
    [MSMV2E3D_climate_faceplate.3mf, climate_faceplate.scad, climate_faceplate.stl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]
2021-06-26 Relay cover
    [climate_bracket.scad, climate_combined.scad, climate_faceplate.scad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]
2021-06-27 Global placeholder and support bools
    [climate_bracket.scad, climate_faceplate.scad]
2021-06-27 Minor fixes
    [climate_bracket.scad, climate_faceplate.scad, relay_cover.scad]
2021-06-28 Relay sidewalls
    [climate_bracket.scad]
2021-06-28 Relay connector openings
    [relay_cover.scad]
2021-06-29 Separated subprojects
    [7-segment_diffuser_test.stl, 7-segment_layout.dxf, 7-segment_layout.scad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]
2021-07-28 Reworked relay cover
    [climate_bracket.scad, climate_bracket.stl, climate_bracket_supports.stl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]
2021-08-01 Enclosure v2.5
    [MSMV2E3D_climate_bracket.3mf, MSMV2E3D_climate_faceplate.3mf, climate_combined.scad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]
2021-08-01 Fixed relay cover screw head clearance, inset depth
    [climate_bracket.scad]
2021-08-02 Misc fixes
    [relay_cover.stl]
2021-08-02 Reverting relay outline changes
2021-08-02 Fixed dial_stem_r, relay hole tolerances, simplified relay mount hole depth
    [climate_bracket.scad, climate_bracket.stl, climate_bracket_supports.stl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]
2021-08-03 Changed faceplace threaded inserts from M3 to M2
2021-08-03 Max IC keepout
    [climate_faceplate.scad]
2021-08-03 Added display well tolerance adjustment
    [climate_faceplate.scad]
2021-08-03 Hook slot bevels
    [climate_bracket.scad]
2021-08-03 Added faceplace alignment adjustment
    [climate_faceplate.scad, dial.scad]
2021-08-04 Increased bezel depth to accommodate ESP backpack. Print set v2.7
    [climate_bracket.stl, climate_bracket_supports.stl, climate_faceplate.scad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]
2021-08-06 Fixed radius/diameter transposition on mounting stems
    [climate_bracket.stl, climate_bracket_supports.stl, climate_faceplate.stl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]
2021-08-06 Dial stem adjustment
    [MSMV2E3D_climate_faceplate.3mf, dial.stl]
2021-08-06 Dial project file
    [MSMV2E3D_dial.3mf]
2021-08-08 Dial stem adjustments
    [dial.stl]
2021-08-10 Cleanup, refactor, relay conn passthrough
    [climate_bracket.scad, climate_faceplate.scad]
2021-08-16 Relay cover AC taps
    [relay_cover.scad]
2021-08-16 Relay front cover. v2.9 renders.
    [climate_bracket.stl, climate_bracket_supports.stl, relay_cover.scad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]
2021-08-17 Switched DHT mount from tab to PCB, resized for direct threading. v2.9 renders
    [climate_faceplate.scad, climate_faceplate.stl, climate_faceplate_supports.stl]
2021-08-18 Added display timer feature
    [MSMV2E3D_climate_faceplate.3mf]
2021-08-18 Added software reset switch
2021-08-19 v2.9 render
    [MSMV2E3D_climate_bracket.3mf]
2021-08-23 Explicitly defined sensor model
2021-08-28 Added PSU Enclosure
    [PSU.scad, PSU.stl]
2021-08-29 Fixed PSU Enclosure
    [PSU.scad, PSU.stl]
2021-08-29 PSU Cover
    [PSU.scad, PSU_cover.scad, PSU_cover.stl]
2021-08-31 Added 5mm depth to faceplace
    [MSMV2E3D_climate_faceplate.3mf, climate_faceplate.stl]
2021-09-03 Living room polynomial calibration
2021-09-03 Larger relay conn passthough, shallower relay bracket
2021-09-03 v3.1 Renders
    [MSMV2E3D_climate_bracket.3mf, climate_bracket.stl]
2021-09-06 Unflatten bracket, reposition relay passthrough, thicker jbox ears
    [climate_bracket.stl]
2021-10-19 Updated Cura project
    [MSMV2E3D_climate_bracket.3mf]
2021-10-19 Added Bill of materials
2021-10-25 Added power failure persistence to settings
    [climate-alphaden.yaml]
2021-10-25 Synced power failure persistence changes to all rooms
    [climate-goatsummit.yaml, climate-livingroom.yaml, climate-wolfdungeon.yaml]
2021-12-13 Remove reboot switch
2021-12-13 Updated test thermostat for board v4.1F
2021-12-13 Changed GPIO names and board type
2021-12-23 Added level shifter to PCB, updated GPIOs
2021-12-24 Power metering
2021-12-27 Added current metering sensors
2022-01-23 (Possibly) fixed race condition
    [climate-goatsummit.yaml, climate-livingroom.yaml, climatetest-2.yaml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]
2022-12-30 Disabled status LED
2023-01-27 Disabled relay control, onboarded api control
2023-09-30 Backported fix for boot-time display update race condition to target board v3.0 (NodeMCU)
    [climate-wolfdungeon.yaml]

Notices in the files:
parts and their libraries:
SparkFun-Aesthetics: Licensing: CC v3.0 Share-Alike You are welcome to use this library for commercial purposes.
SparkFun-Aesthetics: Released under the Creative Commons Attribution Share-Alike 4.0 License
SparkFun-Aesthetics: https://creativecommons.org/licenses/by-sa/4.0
